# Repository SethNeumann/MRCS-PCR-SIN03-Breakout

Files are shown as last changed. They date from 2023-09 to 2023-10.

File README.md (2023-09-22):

# REPO NAME:     MRCS-PCR-SIN03-Breakout

## License: Creative Commons Attribution-NonCommercial-ShareAlike

This board is to provide a neater and more reliable mounting for the PCR-SIN03 ringing generators often found on eBay,
the board has a barrel jack so the module can be powered by a wall wart, a voltage divider to provide 5V for the INHibit line
to gate ringing or create a cadence. There is also an 8 position 0.100 connector for power, daisy chain, INH/5VR and ringing output.

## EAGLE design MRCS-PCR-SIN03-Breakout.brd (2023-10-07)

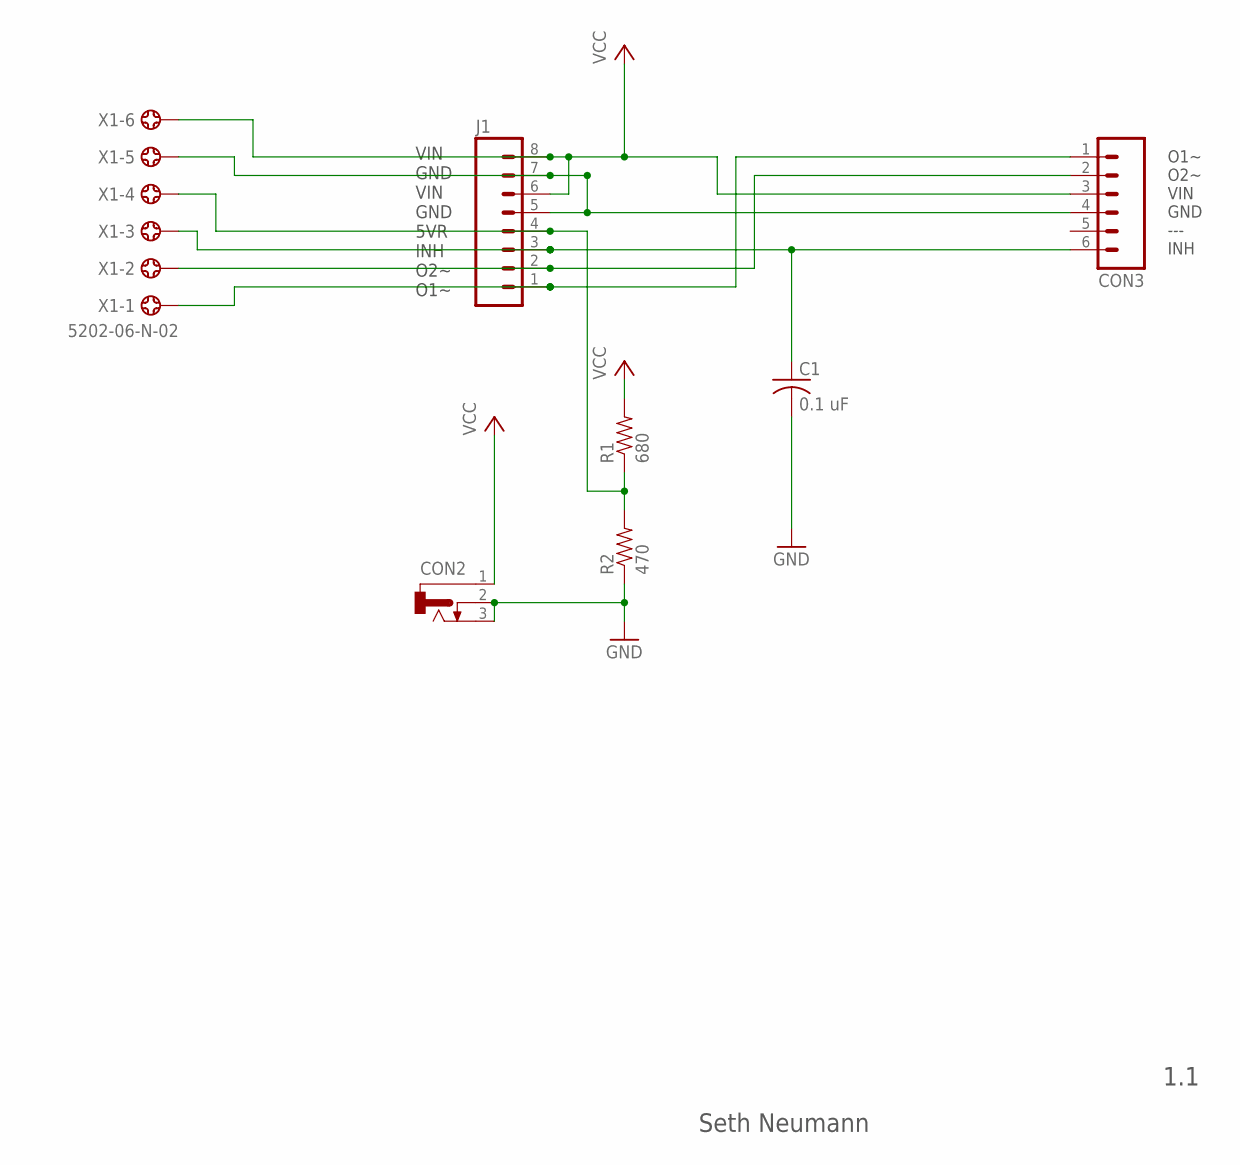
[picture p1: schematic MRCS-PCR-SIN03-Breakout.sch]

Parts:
C1: 0.1 uF; C-PTH-0.100
CON2: CONNECTOR-DC-POWER-RA; DCJ0202
CON3: CONNECTOR-M06POLAR; MOLEX-1X6
J1: CONNECTOR-M08LOCK; 1X08_LOCK
R1: 680; AXIAL-0.4-RES
R2: 470; AXIAL-0.4-RES
X1: 5202-06-N-02

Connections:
5VR: J1.4, R1.P$1 (1), R2.P$2 (2), X1.4
GND: C1.2, CON2.2, CON2.3, CON3.4, J1.5, J1.7, R2.P$1 (1), X1.5
INH: C1.1, CON3.6, J1.3, X1.3
O1: CON3.1, J1.1, X1.1
O2: CON3.2, J1.2, X1.2
VCC: CON2.1, CON3.3, J1.6, J1.8, R1.P$2 (2), X1.6

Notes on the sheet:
Seth Neumann
1.1
VIN GND VIN GND 5VR INH O2~ O1~
O1~ O2~ VIN GND --- INH

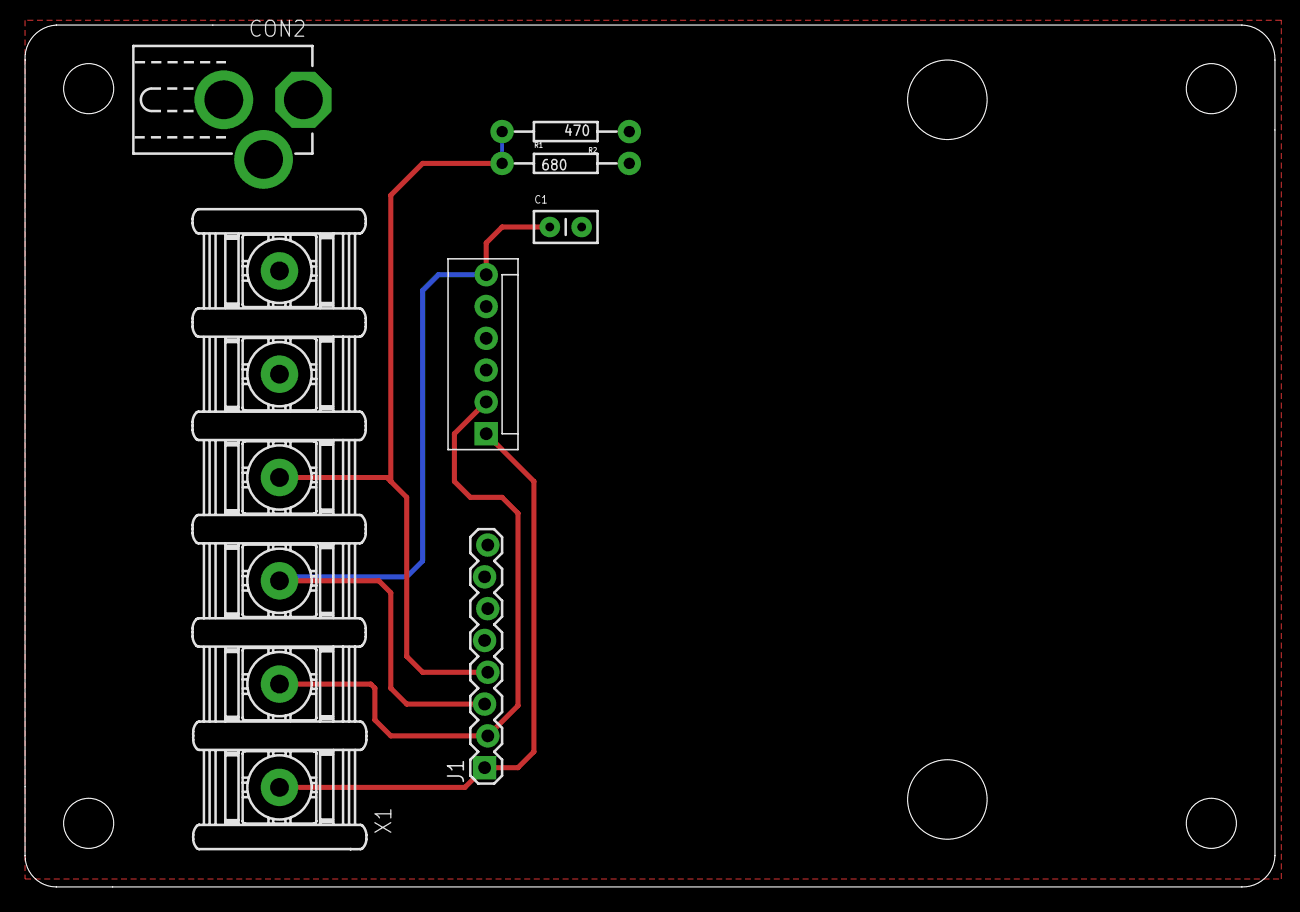
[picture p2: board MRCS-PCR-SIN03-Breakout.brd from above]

Board: 2 copper layers, 99.8 x 68.8 mm, 11 parts (0 on the bottom side), 6 nets.

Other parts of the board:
U$1: BOARD-DINRAIL-2.7IN
U$2: MRCSLOGOTOP
U$3: CA-PROP65WARNING
U$4: MRCSLOGOBTM

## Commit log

2023-09-22 moved work files into Github
    creating new repository
    [EagleTemplate-new.brd, EagleTemplate-new.sch, MRCS-PCR-SIN03-Breakout.brd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]
2023-10-07 changes for 1st board run
2023-10-07 Added 8 mm screw barrier block
    this might be more useful for the phone folks as it supports spade lugs. Plenty of room on the board!
    [MRCS-PCR-SIN03-Breakout.brd, MRCS-PCR-SIN03-Breakout.sch]
